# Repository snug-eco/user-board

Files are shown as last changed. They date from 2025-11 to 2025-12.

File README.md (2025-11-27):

# Snug User Board

KiCad schematic and PCB layout for the snug user board.
This board is intended for private single-person use.
Kernel flashing is supported through the AVR ISP IDC socket.
Terminal UART work over USB serial through a USB-B socket,
which also provides power for the board.
During operation, the board switches its SPI bus to the SD-Card slot.
Port C of the ATmega1284 is broken out to a 10-Pin socket
and can thus be appropriated by the user for additional functionality.

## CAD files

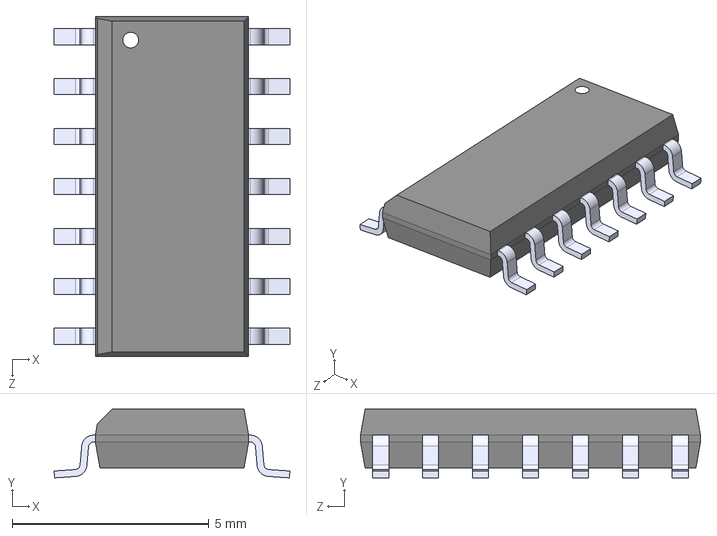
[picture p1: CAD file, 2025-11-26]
MCP2221A_I_SL/MCP2221A-I_SL.step
6.00 x 1.75 x 8.65 mm

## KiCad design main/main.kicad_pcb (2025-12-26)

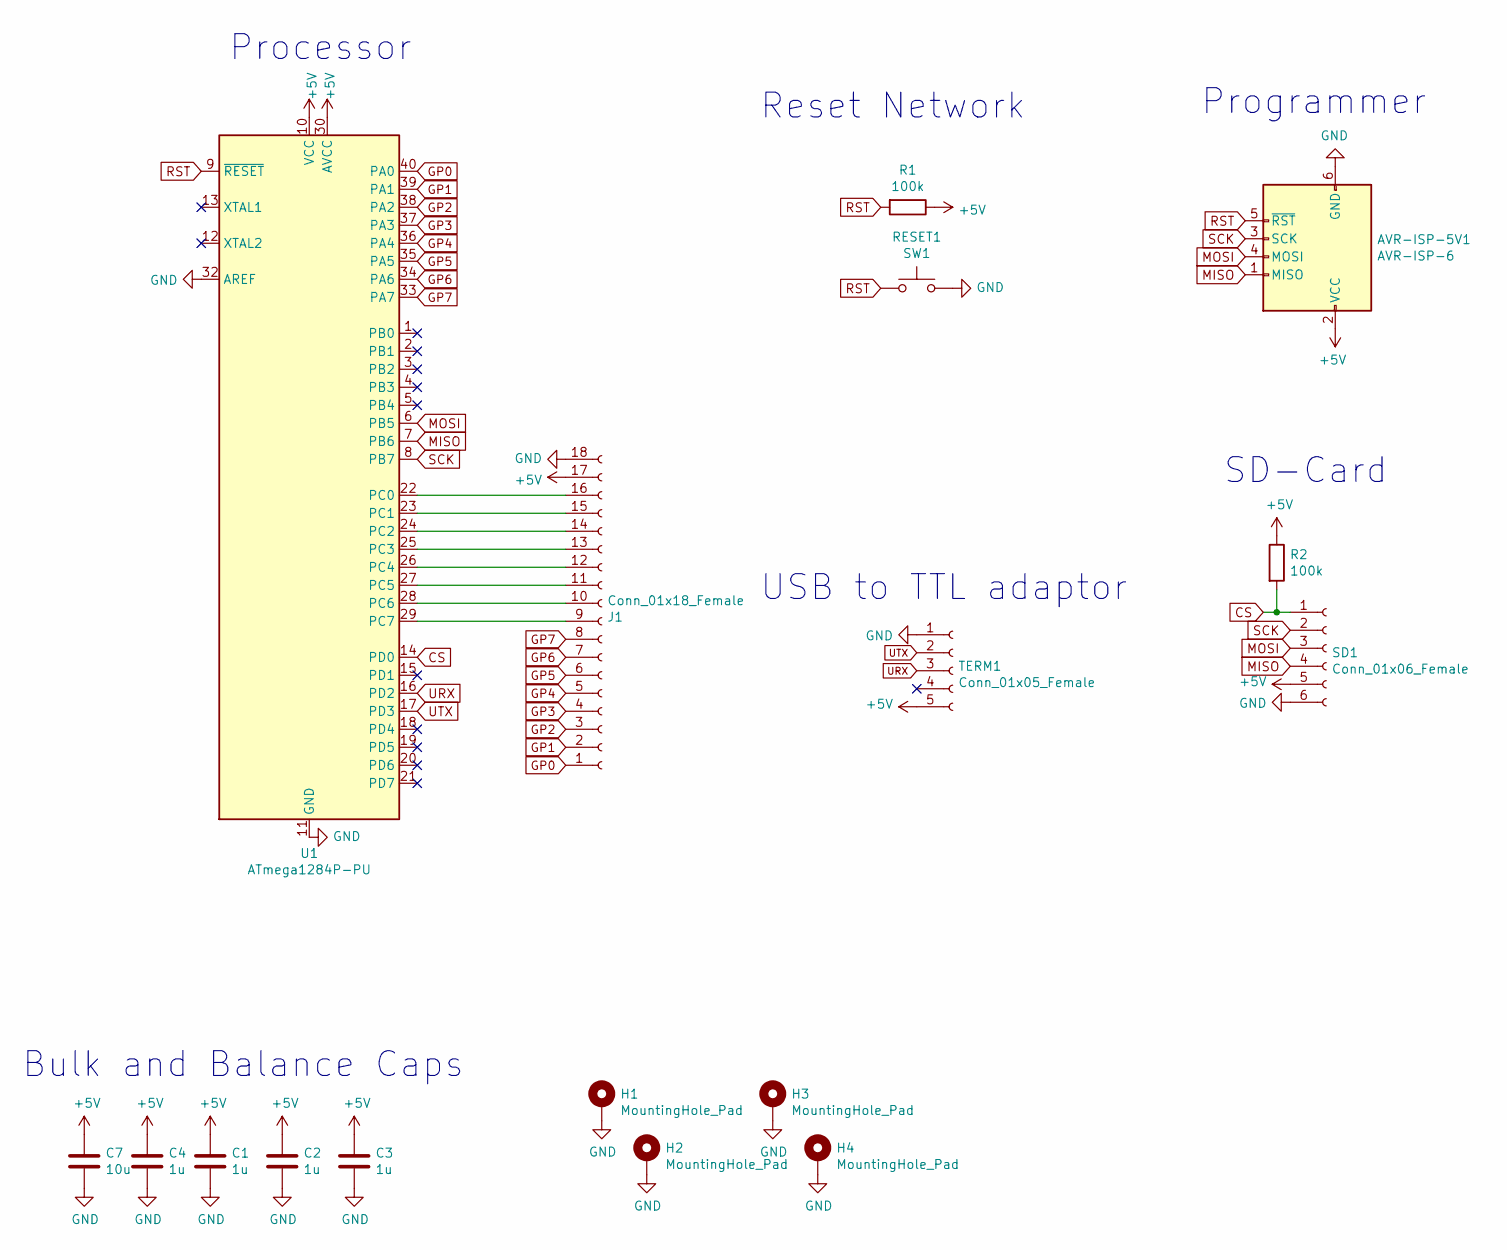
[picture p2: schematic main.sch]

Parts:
AVR-ISP-5V1: AVR-ISP-6; IDC-Header_2x03_P2.54mm_Vertical
C1, C2, C3, C4: 1u; C_1206_3216Metric
C7: 10u; C_1206_3216Metric
H1, H2, H3, H4: MountingHole_Pad; MountingHole_3.2mm_M3_DIN965_Pad
J1: Conn_01x18_Female; PinHeader_1x18_P2.54mm_Vertical
R1, R2: 100k; R_1210_3225Metric
RESET1: SW1; SW_PUSH_6mm_H4.3mm
SD1: Conn_01x06_Female; PinHeader_1x06_P2.54mm_Vertical
TERM1: Conn_01x05_Female; PinSocket_1x05_P2.54mm_Vertical
U1: ATmega1284P-PU; DIP-40_W15.24mm_Socket

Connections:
+5V: AVR-ISP-5V1.2 (VCC), C1.1, C2.1, C3.1, C4.1, C7.2, J1.17, R1.1, R2.1, SD1.5, TERM1.5, U1.10 (VCC), U1.30 (AVCC)
CS: R2.2, SD1.1, U1.14 (PD0)
GND: AVR-ISP-5V1.6 (GND), C1.2, C2.2, C3.2, C4.2, C7.1, H1.1, H2.1, H3.1, H4.1, J1.18, RESET1.2, SD1.6, TERM1.1, U1.11 (GND), U1.31 (GND), U1.32 (AREF)
GP0: J1.1, U1.40 (PA0)
GP1: J1.2, U1.39 (PA1)
GP2: J1.3, U1.38 (PA2)
GP3: J1.4, U1.37 (PA3)
GP4: J1.5, U1.36 (PA4)
GP5: J1.6, U1.35 (PA5)
GP6: J1.7, U1.34 (PA6)
GP7: J1.8, U1.33 (PA7)
MISO: AVR-ISP-5V1.1 (MISO), SD1.4, U1.7 (PB6)
MOSI: AVR-ISP-5V1.4 (MOSI), SD1.3, U1.6 (PB5)
unnamed: J1.9, U1.29 (PC7)
unnamed: J1.10, U1.28 (PC6)
unnamed: J1.11, U1.27 (PC5)
unnamed: J1.12, U1.26 (PC4)
unnamed: J1.13, U1.25 (PC3)
unnamed: J1.14, U1.24 (PC2)
unnamed: J1.15, U1.23 (PC1)
unnamed: J1.16, U1.22 (PC0)
RST: AVR-ISP-5V1.5 (~RST), R1.2, RESET1.1, U1.9 (~RESET)
SCK: AVR-ISP-5V1.3 (SCK), SD1.2, U1.8 (PB7)
URX: TERM1.3, U1.16 (PD2)
UTX: TERM1.2, U1.17 (PD3)

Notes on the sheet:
Processor
Bulk and Balance Caps
Reset Network
Programmer
SD-Card
USB to TTL adaptor

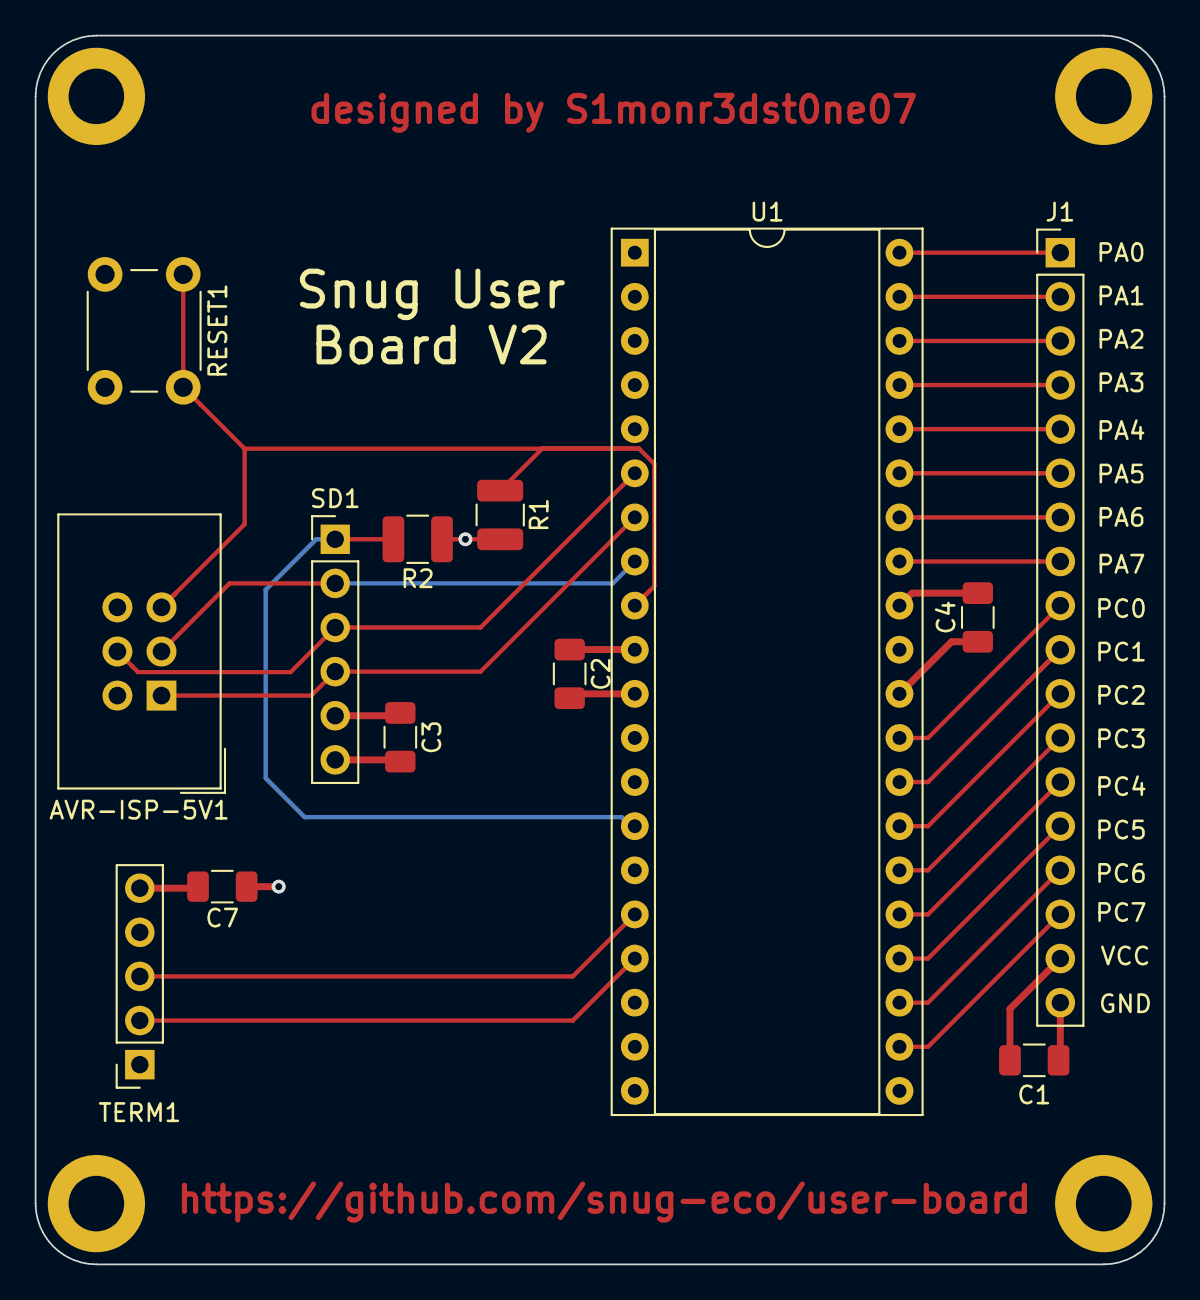
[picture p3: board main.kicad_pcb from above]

Board: 4 copper layers, 65.0 x 70.8 mm, 17 parts (0 on the bottom side), 25 nets.

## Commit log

2025-11-26 finished general board schematic
    [main.sch]
2025-11-26 fixed footprints
    [main.kicad_pcb, main.sch]
2025-11-26 laid out pcb
    [main.kicad_pcb, main.sch]
2025-11-26 added component libraries
    [MCP2221A-I_SL.step]
2025-11-27 added mounting holes
    [main.kicad_pcb, main.sch]
2025-11-27 fixed 3.3v regulator cap
    [main.kicad_pcb, main.sch]
2025-11-27 fixed bulking caps
    [main.kicad_pcb, main.sch]
2025-11-27 fixed stuff
    [main.kicad_pcb]
2025-11-27 fixed sd card footprint
2025-11-27 fixed layout
    [main.kicad_pcb]
2025-11-27 added gerbers directory to gitignore
2025-11-28 fixed component fp text
    [main.kicad_pcb]
2025-11-28 annotated schematic
    [main.sch]
2025-12-02 fixed silkscreen stuff
    [main.kicad_pcb]
2025-12-02 fixed sd card pad distance
    [main.kicad_pcb]
2025-12-23 designed V2
    [main.kicad_pcb, main.sch]
2025-12-26 removed unnecessary usb-b port
    [main.kicad_pcb, main.sch]
